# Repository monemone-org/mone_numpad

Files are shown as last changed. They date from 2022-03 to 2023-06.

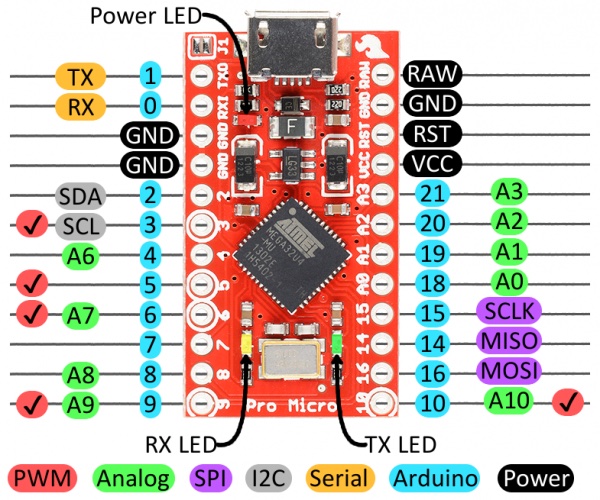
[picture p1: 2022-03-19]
schematics/Spark Pro Miro Pins.jpg

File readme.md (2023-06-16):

# mone_numpad

## Introduction
Mone_numpad is a handwired numpad with a volume dial that runs a custom VIAL/QMK firware. It can control the machine's input and output volume.

* the electronic design and schematic 
* The STL for the case
* The custom VIAL/QMK firmware
* A Windows desktop notification icon software that can help the numpad to control the followings:
    * default audio output volume control
    * default audio input volume control
    * volumne control for active applications with audio channels

[toc]

## Projects/

### keyboard-layout_editor/

It contains the json file for [keyboard-layout_editor](http://www.keyboard-layout-editor.com)

### schematics/

Mone_numpad's Wiring schematics

### stl/

Modified docukboard STL for mone_numpad

### vial layouts/

vial layout files

### vial-qmk/

A modified forted version of vial-qmk. It added supports for

1. Mac Fn key
2. Custom command prefix for mone_numpad
3. intercepting vial_encoder_update()

### vial-qmk-keyboards-monenumpad/

The firware code for mone_numpad.

See: `compile_monenumpad_vial.sh` for build steps.

### desktop/

Code for the desktop companion app for mone_numpad

#####  desktop/NotificationIcon

* NotificationIcon is the Win32 desktop companion app for mone_numpad.
* It provides the following functionalities:
	* displays as an notification icon on the taskbar.
	* provides volumn channel info to monenumpad:
 		1. default output
   		2. default input
   		3. active applications tha has volume channels

##### desktop/USBDeviceSwift/RaceflightControllerHIDExample
* A modified Swift sample app to help test monenumpad's customized vial/qmk firmware on Mac.

##### desktop/hidapi

A cutomized fork of hidapi (an open source project) with the following changes.

* 1 byte packing C struct. 
	* At one point, I was writing C# and Swift clients.  Changing the byte packing to 1 byte made it easier to marshel the C structure data to/from C# and Swift.

* added support to send notifications when a HID device is connected/disconnected.

	```C++
		
	typedef struct on_added_device_callback_entry {
		void (*on_added_device)(struct hid_device_info*, void* user_data);
		void* user_data;
	} on_added_device_callback_entry;

	struct hid_device_info HID_API_EXPORT * HID_API_CALL hid_enumerate_ex(
																		unsigned short vendor_id,
																		unsigned short product_id,
																		unsigned short usage_page,
																		unsigned short usage,
																		on_added_device_callback_entry on_added_device_callback);
	void HID_API_EXPORT HID_API_CALL hid_stop_enumerate_on_added_device_callback();

	typedef struct on_disconnected_callback_entry {
		void* user_data;
		void (*on_disconnected)(hid_device*, void* user_data);
	} on_disconnected_callback_entry;

	int HID_API_EXPORT hid_register_disconnected_callback(hid_device *dev, on_disconnected_callback_entry on_disconnected);
	void HID_API_EXPORT hid_unregister_disconnected_callback(hid_device *dev);

	int HID_API_EXPORT_CALL hid_get_max_report_length(hid_device *dev);

	```

* added support to send notifications when an input record is read from a HID device.
	```C++

		typedef struct on_read_callback_entry {
			void* user_data;
			void (*on_read)(hid_device*, unsigned char*, size_t, void* user_data);
			void (*on_read_failure)(hid_device*, const wchar_t* pszMessage, void* user_data);
		} on_read_callback_entry;

        int HID_API_EXPORT HID_API_CALL hid_register_read_callback(hid_device *dev, on_read_callback_entry on_read);
        void HID_API_EXPORT HID_API_CALL hid_unregister_read_callback(hid_device *dev);

	```
##### desktop/xcodeProj
* the xcodeproj for `desktop/hidapi` to helpe edit and build on Mac

##### desktop/monenumpad_desktop

The original C# POC test client app before I switched to develop `NotificationIcon`.  

My original plan was to create a C# desktop app to talk to monenum_pad via hidapi. I got the marshalling code working. However C# WinForm (or any C# Windows client framework) does not have easy support to add an icon to the taskbar's notification area.  The easiest way is still Win32. So I created `NotificationIcon` instead and abandoned this project.

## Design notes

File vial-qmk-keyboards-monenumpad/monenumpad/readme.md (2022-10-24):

# monenumpad

monenumpad

*A short description of the keyboard/project*

* Keyboard Maintainer: [monehsieh](https://github.com/monehsieh)
* Hardware Supported: *The PCBs, controllers supported*
* Hardware Availability: *Links to where you can find this hardware*

Install qmk

    git clone https://github.com/vial-kb/vial-qmk.git

Make example for this keyboard (after setting up your build environment):

    make monenumpad:vial

Flashing example for this keyboard:

    make monenumpad:vial:flash

See the [build environment setup](https://docs.qmk.fm/#/getting_started_build_tools) and the [make instructions](https://docs.qmk.fm/#/getting_started_make_guide) for more information. Brand new to QMK? Start with our [Complete Newbs Guide](https://docs.qmk.fm/#/newbs).

See [VIAL Porting Build](https://get.vial.today/docs/)

## Bootloader

Enter the bootloader in one of the following ways:

* **Physical reset button**: Briefly press the button on the back of the PCB - some may have pads you must short instead
* **Ground reset pin**: Short GND and RESET pin on the micro controller (the right top 2 pin when view from the bottom of the numpad)

Behaviour:

1. rotary encoder: change current session volume
2. press and hold fn key: switch to next layer
3. press fn: switch to next session
4. press asterisk while holding fn key: switch between win/mac mode

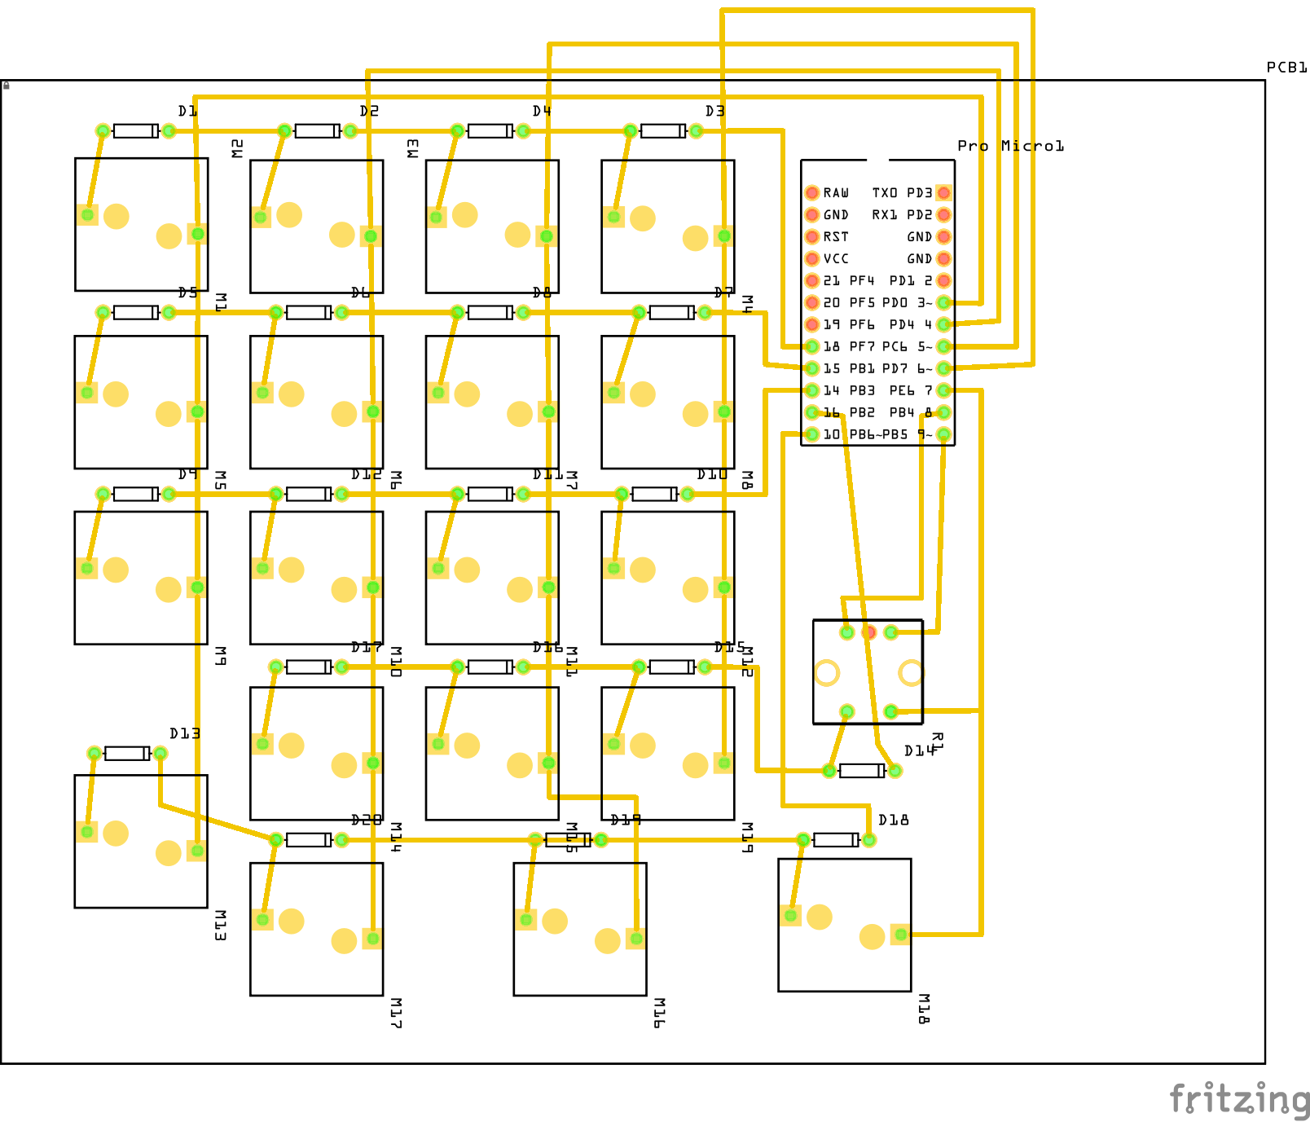
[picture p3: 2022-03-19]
schematics/Sketch v1_pcb.png

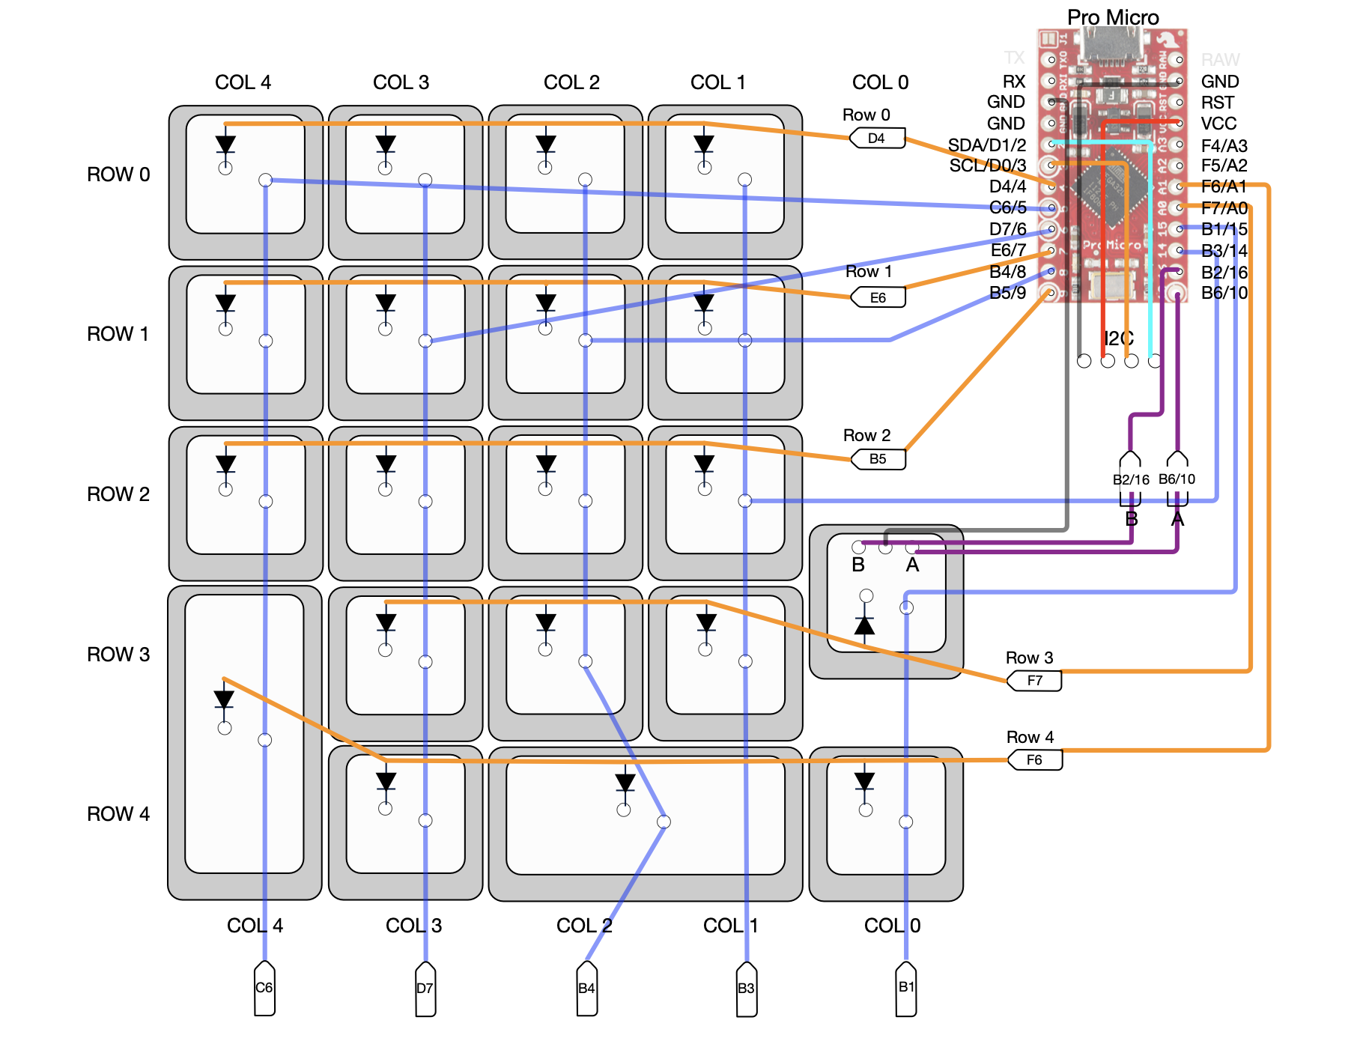
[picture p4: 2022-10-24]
schematics/monenumpad_v5.png

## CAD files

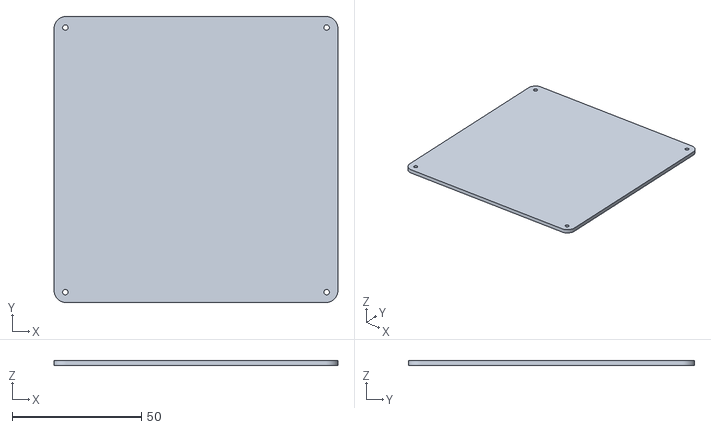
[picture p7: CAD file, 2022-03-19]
stl/duckboard_bottom.stl
109.6 x 110.5 x 2.00

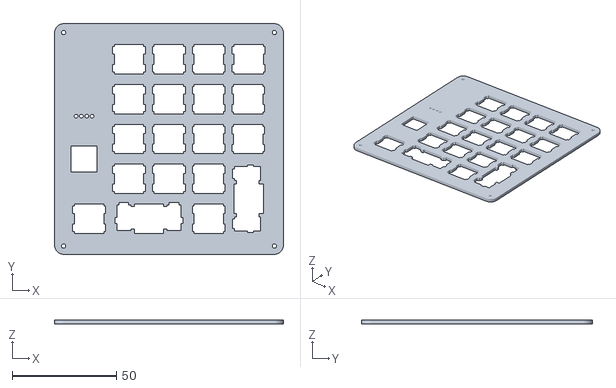
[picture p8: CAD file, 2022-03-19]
stl/duckboard_top.stl
109.6 x 110.5 x 2.00

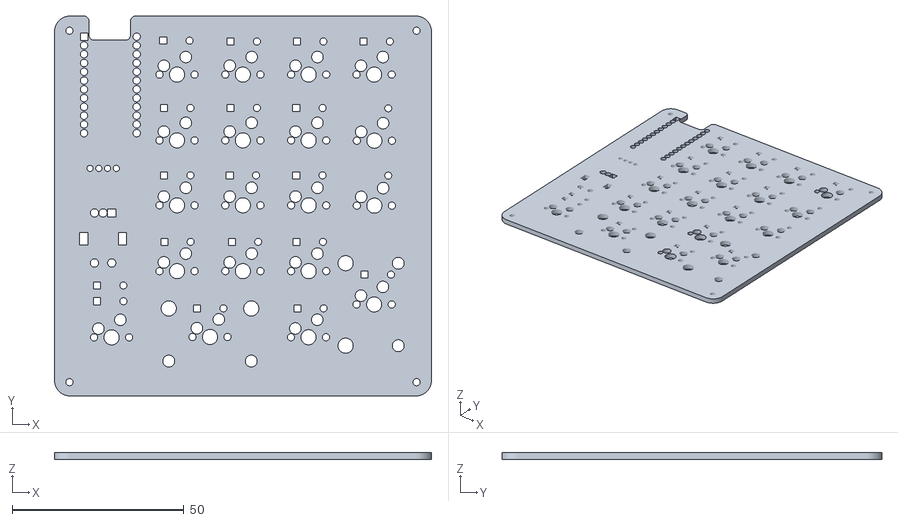
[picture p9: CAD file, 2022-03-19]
stl/duckboard_mid.stl
109.6 x 110.5 x 2.00

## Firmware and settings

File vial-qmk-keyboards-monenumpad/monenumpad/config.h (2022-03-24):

// Copyright 2022 monehsieh (@monehsieh)
// SPDX-License-Identifier: GPL-2.0-or-later

#pragma once

#include "config_common.h"


/**
        if (hid->product >= USB_DEVICE_ID_APPLE_WELLSPRING4_ANSI &&
                hid->product <= USB_DEVICE_ID_APPLE_WELLSPRING4A_JIS)
            table = macbookair_fn_keys;
        else if (hid->product < 0x21d || hid->product >= 0x300)
            table = powerbook_fn_keys;
        else
            table = apple_fn_keys;

*/
#define USB_VENDOR_ID_APPLE      0x05ac
#define USB_PRODUCT_ID_APPLE     0x029c
#define VENDOR_ID    0x05ac //Apple VenderID for Fn key to work as world button 
#define PRODUCT_ID   0x029c //Apple M1 Macbookpro keyboard product ID 

/**
 * A suggested method of choosing a unique VENDOR_ID is choosing two letters from the keyboard’s
 *  designer/vendor name and using the two 8-bit ASCII values of these letters
 * 
 *  Designer: monehsieh
 *  ASCII for "mh": 0x6D 0x68
 * 
 * 
 */
// #define VENDOR_ID    0x6D68   // "mh" = monehsieh
// #define PRODUCT_ID   0x0001

// version 1: qmk, basic keypad
// version 2: vial
// version 3: custom keycode with shortcuts for YouTube, iOS and Func keys
#define DEVICE_VER   0x0003      
#define MANUFACTURER monehsieh
#define PRODUCT      monenumpad

/* key matrix size */
#define MATRIX_ROWS 5
#define MATRIX_COLS 5

/*
 * Keyboard Matrix Assignments
 *
 * Change this to how you wired your keyboard
 * COLS: AVR pins used for columns, left to right
 * ROWS: AVR pins used for rows, top to bottom
 * DIODE_DIRECTION: COL2ROW = COL = Anode (+), ROW = Cathode (-, marked on diode)
 *                  ROW2COL = ROW = Anode (+), COL = Cathode (-, marked on diode)
 *
 */

#define MATRIX_ROW_PINS { D4, E6, B5, F7, F6 }
#define MATRIX_COL_PINS { B3, B1, B4, D7, C6 }
#define UNUSED_PINS

/* COL2ROW or ROW2COL */
//#define DIODE_DIRECTION COL2ROW
#define DIODE_DIRECTION ROW2COL

#define ENCODERS_PAD_A { B6 }
#define ENCODERS_PAD_B { B2 }
#define ENCODER_RESOLUTION 4

// # OLED driver SSD1306
// # High resolution: 128 x 64 
// OLED_ENABLE = yes
// OLED_DRIVER = SSD1306


/*
 * Split Keyboard specific options, make sure you have 'SPLIT_KEYBOARD = yes' in your rules.mk, and define SOFT_SERIAL_PIN.
 */
#define SOFT_SERIAL_PIN D0  // or D1, D2, D3, E6

//#define LED_NUM_LOCK_PIN B0
//#define LED_CAPS_LOCK_PIN B1
//#define LED_SCROLL_LOCK_PIN B2
//#define LED_COMPOSE_PIN B3
//#define LED_KANA_PIN B4

//#define BACKLIGHT_PIN B7
//#define BACKLIGHT_LEVELS 3
//#define BACKLIGHT_BREATHING

//#define RGB_DI_PIN E2
//#ifdef RGB_DI_PIN
//#    define RGBLED_NUM 16
//#    define RGBLIGHT_HUE_STEP 8
//#    define RGBLIGHT_SAT_STEP 8
//#    define RGBLIGHT_VAL_STEP 8
//#    define RGBLIGHT_LIMIT_VAL 255 /* The maximum brightness level */
//#    define RGBLIGHT_SLEEP  /* If defined, the RGB lighting will be switched off when the host goes to sleep */
/*== all animations enable ==*/
//#    define RGBLIGHT_ANIMATIONS
/*== or choose animations ==*/
//#    define RGBLIGHT_EFFECT_BREATHING
//#    define RGBLIGHT_EFFECT_RAINBOW_MOOD
//#    define RGBLIGHT_EFFECT_RAINBOW_SWIRL
//#    define RGBLIGHT_EFFECT_SNAKE
//#    define RGBLIGHT_EFFECT_KNIGHT
//#    define RGBLIGHT_EFFECT_CHRISTMAS
//#    define RGBLIGHT_EFFECT_STATIC_GRADIENT
//#    define RGBLIGHT_EFFECT_RGB_TEST
//#    define RGBLIGHT_EFFECT_ALTERNATING
/*== customize breathing effect ==*/
/*==== (DEFAULT) use fixed table instead of exp() and sin() ====*/
//#    define RGBLIGHT_BREATHE_TABLE_SIZE 256      // 256(default) or 128 or 64
/*==== use exp() and sin() ====*/
//#    define RGBLIGHT_EFFECT_BREATHE_CENTER 1.85  // 1 to 2.7
//#    define RGBLIGHT_EFFECT_BREATHE_MAX    255   // 0 to 255
//#endif

/* Debounce reduces chatter (unintended double-presses) - set 0 if debouncing is not needed */
#define DEBOUNCE 5

/* define if matrix has ghost (lacks anti-ghosting diodes) */
//#define MATRIX_HAS_GHOST

/* Mechanical locking support. Use KC_LCAP, KC_LNUM or KC_LSCR instead in keymap */
#define LOCKING_SUPPORT_ENABLE
/* Locking resynchronize hack */
#define LOCKING_RESYNC_ENABLE

/* If defined, GRAVE_ESC will always act as ESC when CTRL is held.
 * This is useful for the Windows task manager shortcut (ctrl+shift+esc).
 */
//#define GRAVE_ESC_CTRL_OVERRIDE

/*
 * Force NKRO
 *
 * Force NKRO (nKey Rollover) to be enabled by default, regardless of the saved
 * state in the bootmagic EEPROM settings. (Note that NKRO must be enabled in the
 * makefile for this to work.)
 *
 * If forced on, NKRO can be disabled via magic key (default = LShift+RShift+N)
 * until the next keyboard reset.
 *
 * NKRO may prevent your keystrokes from being detected in the BIOS, but it is
 * fully operational during normal computer usage.
 *
 * For a less heavy-handed approach, enable NKRO via magic key (LShift+RShift+N)
 * or via bootmagic (hold SPACE+N while plugging in the keyboard). Once set by
 * bootmagic, NKRO mode will always be enabled until it is toggled again during a
 * power-up.
 *
 */
//#define FORCE_NKRO
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

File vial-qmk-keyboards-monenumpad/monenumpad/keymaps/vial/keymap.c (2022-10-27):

// Copyright 2022 monehsieh (@monehsieh)
// SPDX-License-Identifier: GPL-2.0-or-later

#include QMK_KEYBOARD_H

#include <stdio.h>
#include <string.h>

#include "user_config.h"
#include "press_and_hold_key.h"
#include "mone_keys.h"
#include "maxmix/maxmix.h"

#define min(a, b) \
    ((a) < (b) ? (a) : (b));

/**
 * Behaviour descriptions:
 * 
 * 1. Pressing and holding key (r=0, c=4) will change layers
 * 
 * 2. Turning rotary encoder while holding key (r=0, c=4) also changes layers.
 *    Turning clockwise advances to the next layer. Turning anti-clockwise 
 *    will move to previous layer.
 * 
 * 3. Pressing rotary encoder while holding key (r=0, c=4) will toggle the 
 *    platform mode between Win and Mac, which affects the pre-programmed key
 *    shortcuts.
 * 
 */


/**
 * Windows Shortcuts:
 * Fn + DEL to increase the brightness and Fn + Backspace to decrease it.
 * On Dell XPS laptop keyboard (pictured below), hold the Fn key and press F11 or F12 to adjust the brightness of the screen
 */


// Defines names for use in layer keycodes and the keymap
enum layers {
    _BASE,
    _FN1,
    _FN2,
    _FN3,
    _LAST = _FN3
};


const char* layer_names[] = {
    "Base",
    "YouTube",
    "iOS",
    "Fn Keys"
};

/*
#define LAYOUT( \
         K01, K02, K03, K04, \
         K11, K12, K13, K14, \
         K21, K22, K23, K24, \
    K30, K31, K32, K33, \
    K40,   K42,    K43, K44  \
) { \

*/

const uint16_t PROGMEM keymaps[][MATRIX_ROWS][MATRIX_COLS] = {
    /* Base */
//     [_BASE] = LAYOUT(
//            KC_DLR, KC_PERC, KC_PSLS, KC_PAST, 
//            KC_P7,  KC_P8,   KC_P9,   KC_PMNS, 
//            KC_P4,  KC_P5,   KC_P6,   KC_PPLS, 
// KC_MUTE,   KC_P1,  KC_P2,   KC_P3, 
// KC_BSPACE, KC_P0,  KC_PDOT, KC_PENT),
    [_BASE] = LAYOUT(
           KC_DLR, KC_PERC, KC_PSLS,     KC_PAST, 
           KC_7,   KC_8,    KC_9,        KC_PMNS, 
           KC_4,   KC_5,    KC_6,        KC_PPLS, 
KC_MUTE,   KC_1,   KC_2,    KC_3, 
MK_FN,             KC_0,    KC_KP_DOT,   KC_PENT),

// YouTube layer
    [_FN1] = LAYOUT(
            MK_YT_HOME,        MK_YT_SUBSCRIPTNS,  MK_YT_WATCHLATER, MK_YT_HISTORY, 
            MK_YT_PREVCH,      MK_YT_SPEEDUP,      MK_YT_NEXTCH,     KC_BRID, 
            MK_YT_REWIND,      MK_YT_PLAY,         MK_YT_FASTFORWD,  KC_BRIU, 
 _______,   MK_YT_PREVCH,      MK_YT_SPEEDDOWN,    MK_YT_NEXTCH,         
 _______,                      MK_YT_CYCLEVW,      MK_YT_FULLSCVW,   MK_YT_PLAY),


/* iPad Layer   
   MK_IOS_QUICKNOTE, //Quick Note, World+Q
*/
    [_FN2] = LAYOUT(
              MK_IOS_APPSWITCHER, MK_IOS_HOME, MK_IOS_NOTIFICATION, MK_IOS_CONTROLCENTER, 
              MK_IOS_PREVAPP,     KC_UP,       MK_IOS_NEXTAPP,      KC_BRID, 
              KC_LEFT,            MK_IOS_PLAY, KC_RIGHT,            KC_BRIU, 
 _______,     MK_IOS_PREVTRACK,   KC_DOWN,     MK_IOS_NEXTTRACK,  
 _______,                         _______,     MK_IOS_QUICKNOTE,    _______),


/*
    FUNC Key Layer
*/
    [_FN3] = LAYOUT(
              KC_F10,  KC_F11,  KC_F12, _______, 
              KC_F7,   KC_F8,   KC_F9,   KC_BRID, 
              KC_F4,   KC_F5,   KC_F6,   KC_BRIU, 
 _______,     KC_F1,   KC_F2,   KC_F3,  
 _______,              KC_INS,  KC_DEL, _______)

};




//
// Layer management functions
//

// 
// void switchToNextLayer(bool advance)
// param
//      advance:  true, advance to the next layer
//                false, go to the previous layer
//  
void switchToNextLayer(bool advance);
layer_state_t getNextLayer(bool advance);


// bool process_hold_switch_layer_key(uint16_t keycode);
// bool process_tap_switch_layer_key(uint16_t keycode);

bool process_hold_rotary_encoder_key(uint16_t keycode);
bool process_tap_rotary_encoder_key(uint16_t keycode);

bool process_hold_fn_key(uint16_t keycode);
bool process_tap_fn_key(uint16_t keycode);

const keypos_t asterisk_keypos = { .row= 0, .col= 4 };  // * key
const keypos_t fn_keypos = { .row= 4, .col= 0 }; //Fn
press_and_hold_key_t fn_key;

// const keypos_t switch_layer_keypos = { .row= 0, .col= 4 };  // * key
// press_and_hold_key_t switch_layer_key;

const keypos_t rotary_encoder_keypos = { .row= 3, .col= 0 };
press_and_hold_key_t rotary_encoder_key;

bool editing_session_mode = false;


void keyboard_post_init_user(void) 
{    
  // Customise these values to desired behaviour
  debug_enable=true;
  debug_matrix=true;
  //debug_keyboard=true;
  //debug_mouse=true;

  read_user_config();

//   switch_layer_key = make_press_and_hold_key(
//         switch_layer_keypos,
//         process_hold_switch_layer_key,
//         process_tap_switch_layer_key
//     );

    fn_key = make_press_and_hold_key(
        fn_keypos,
        process_hold_fn_key,
        process_tap_fn_key
    );

  rotary_encoder_key = make_press_and_hold_key(
        rotary_encoder_keypos,
        process_hold_rotary_encoder_key,
        process_tap_rotary_encoder_key
    );

  initialize_maxmix();
}
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

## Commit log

2022-03-19 added mone numpad source code and other resources to github
    [Sketch breadboard.fzz, Sketch v1.fzz, Sketch.fzz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]
2022-03-19 moved schematics to a subfolder
    [Sketch breadboard.fzz, Sketch v1.fzz, Sketch.fzz]
2022-03-19 updated schematics on omnigraffle
2022-03-23 1. added Apple Fn key support patch to VIAL 2. added custom defined keycode for Youtube and iOS shortcuts 3. changed layer 1 to Youtube shortcuts, layer 2 to mac/iOS shortcuts and layer 3 to F1 to F9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
    [config.h, keymap.c]
2022-03-24 1. implemented press and hold key(r=0, c=4) and turning the encoder changes layers 2. added a wait() for youtube shortcuts
    [config.h, keymap.c]
2022-03-24 reduced RAM and EEPROM usage #define VIAL_COMBO_ENTRIES 4 reduce binary size #set to no to reduce firmware size MOUSEKEY_ENABLE = no #EXTRAFLAGS+=-flto #define NO_ACTION_MACRO #define NO_ACTION_FUNCT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
    [config.h, keymap.c]
2022-03-26 Added a platform mode (win or mac) in config and persist in eeprom.
    - holding key (r=0,c=4) while pressing rotary encoder button will toggle platform mode between win and mac.
    - added windows Youtube and platform shortcuts when running in win mode.
    [keymap.c]
2022-03-30 refactored press and hold detection code
    1. refactored press and hold detection code to a separate struct (struct press_and_hold_key_t) and group of c functions in press_and_hold_key.h/c
    2. refactored enum mone_keys {} to mone_keys.h/c
    3. created press_and_hold_key_t switch_layer_key and press_and_hold_key_t rotary_encoder_key to help handle press and hold switch layer key and rotary encoder key.
2022-04-14 added custom HID commands to allow change different app/channel's volume with the help of a client app.
    1. defined different commands and data structures for maxmix functionalities.
    2. press and hold encoder key will enter current audio session edit mode.
    3. turning encoder, changes volumne of current audio session.
    other changes:
    1. renamed MONE_ENCODERS_ENABLE to VIAL_MONE_ENCODERS_ENABLE, so it is clear that MONE_ENCODERS_ENABLE depends on Vial's encoder support.
    2. defined different DEBUG_* macros to enable/disable uprint for debugging different functionalities.
2022-04-14 modified a Mac HID communication sample to communicate with monenumpad for POC
2022-05-03 C# desktop app 1. created C# desktop app draft that uses hidapi to talk to the device 2. changed hidapi/Devices.cs to not create a read loop thread. Changed hidapi to use on_read callback. 3. The siz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
    device qmk code
    1. enhanced LCD display to show volume and muted state if known.
    2. fixed data structure size calculation in structs.h
    [keymap.c]
2022-05-03 listen to device disconnect notification and quit test app.
2022-05-03 changed the 2nd combo key to switch platform mode (Win/Mac) to the left bottom Delete key, instead of using the encoder.
2022-09-28 added a branch of qmk from March 14, 2022 for further customization.
    [nose2.cfg]
2022-09-28 intercepted encoder_update_kb to mone_encoder_update to allow us to override the encoder's behaviour
2022-09-28 Added support to handle my own HID commands: id_mone_prefix = 0xFD
    Other changes:
    1. renamed MONE_ENCODERS_ENABLE to VIAL_MONE_ENCODERS_ENABLE to make it clear that MONE_ENCODERS_ENABLE depends on Vial's encoder support.
    2. refactored vial_get_encoder_keycode() to not exec_keycode() and only return the detected keycode. Let its caller vial_encoder_update() to exec_keycode() the obtained the keycode. So my keyboard ca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
2022-09-29 rm src/gmk-firmware because gmk only works in its own git repo. I will have to change it to a git submodule.
    [nose2.cfg]
2022-10-01 added Windows Taskbar notification tray icon sample. We will modify it to our monenumpad desktop app.
2022-10-01 Modified NotificatoinIcon to monitor default in/out audio devices and sessions
    1. added ATL to project
    2. created CMMDevice, CMMSession, CMMDeviceController to keep track of active default in/out audio devices and their sessions
    3. fixed that if NotificatoinIcon crashed before , the next launch may not show the Notification icon on task bar properly. The icon could disappear on mouse over. Fixed by using an unique GUID per launch.
2022-10-01 Race condition bug fixes: 1. fixed a race condition that the MMDevice API's notification is called in a worker thread. This caused race condition when accessing or deleting MM objects. So changed the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
2022-10-23 improvement in keeping track of MMSession connections
    1. added more tracing
    2. if a session state is expired, treats it as if it is disconnected.
    3. renamed class CMMDeviceControllerListener OnMMSessionRefreshed() -> OnMMSessionsAddRemoved() to make it more clear that it only fires when sessions are added/removed, not when session properties a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
    4. handled refreshDevice differently between session changes vs property changes
    5. Removed CMMDeviceController ID
    6. removed IDL file since we don't really use it. It increases compilation time.
2022-10-23 added schematic v5 png
2022-10-24 vial-qmk/keyboards/monenumpads
    1. changed to use __FUNCTION__ in trace messages instead of putting method name in string constants. This helps reduce firmware size.
    2. moved debug macro definition in vial/config.h.
    3. changed SessionData.name size to 25 bytes from 20 bytes
    4. changed OLED rendering code to render session name in 2 lines and truncate names properly if names are too long for display.
    [config.h, keymap.c]
2022-10-24 NotificationIcon fixes
    1. for default out and in master vol, changed to control with MMDevice' s IAudioEndpointVolume interface
    2. on HIDDevice async read failure, get the error message and notify back to KBCommService so it can reconnect to the device.
    3. Make sure the volume value set to MMDevice and MMSession is within range 0..1
2022-10-24 changed numpad key combo to switch sessions and layers
    1. changed the bottom left key from DEL to a custom FN
    2. tapping FN key will change audio session
    3. holding FN key will change layer
    4. tapping asterisk while holding FN will switch between win/mac mode
2022-10-24 fxied that when changing default audio devices, numpad wasnt notified.
